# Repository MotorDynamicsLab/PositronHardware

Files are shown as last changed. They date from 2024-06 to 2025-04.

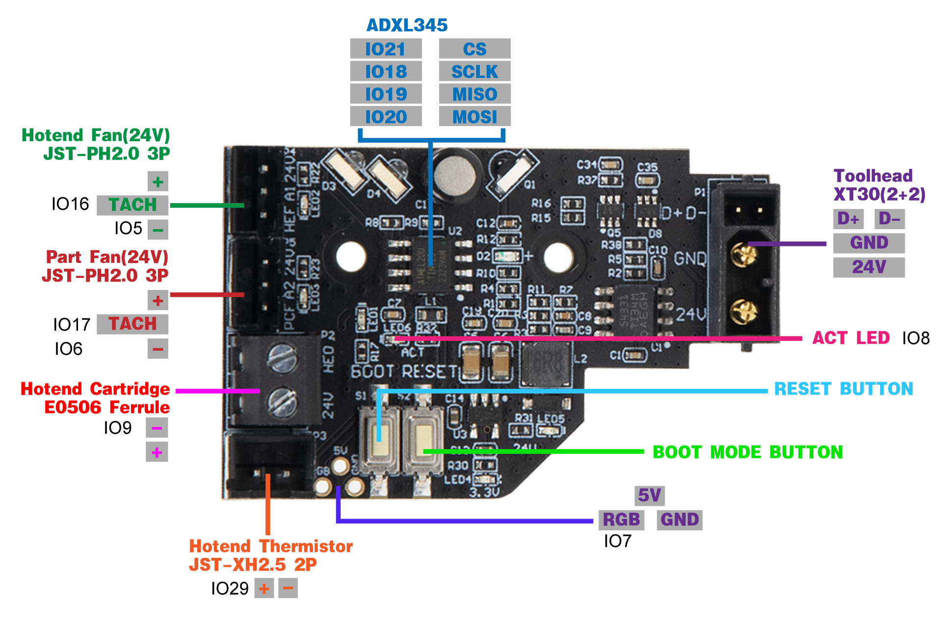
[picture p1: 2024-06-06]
PositronV3.2/Images/Toolboard Pinout.png

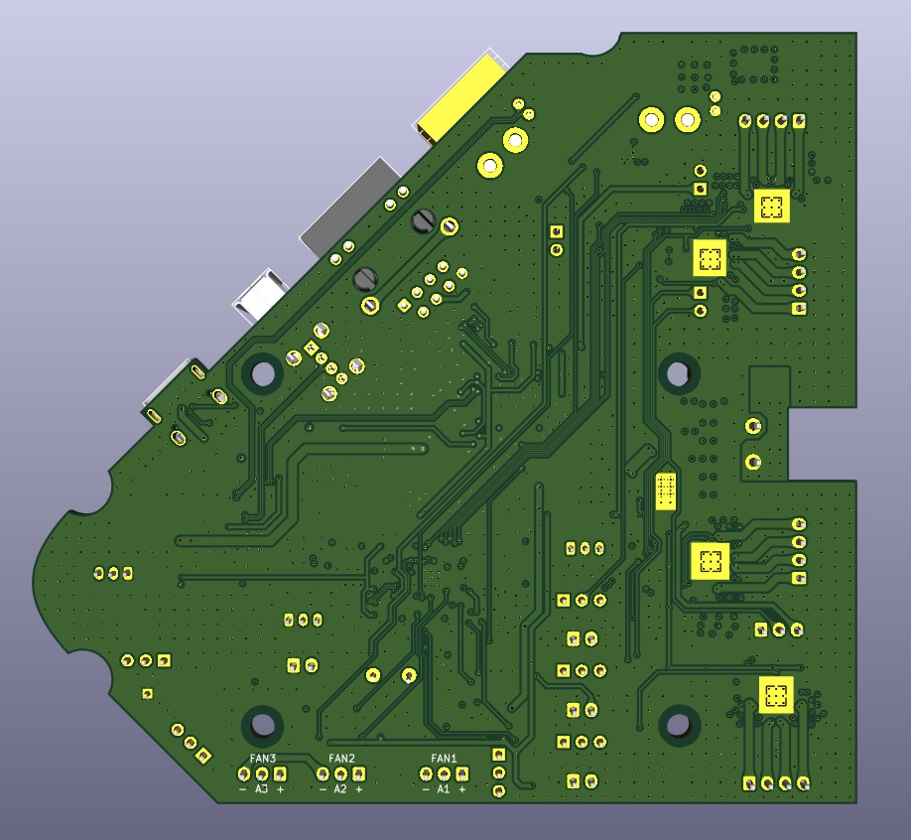
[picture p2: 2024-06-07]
PositronV3.2/Hardware/LDO Positron Mainboard/LDO Positron Mainboard Rev1.1_3D Layout Bottom.jpg

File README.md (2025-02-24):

# Positron Hardware
Contains information and drawings for PCBs used in the LDO Positrons

## Exceptions to CC BY-SA 4.0 for LDO Motors – Positron 3D PCBs

The Positron 3D Team grants an exception to the CC BY-SA 4.0 license for PCBs developed for the Positron 3D printer and manufactured by LDO Motors under the following conditions:
1. Limited Scope: This exception applies only to PCB designs developed by the Positron 3D Team and manufactured by LDO Motors. All other components remain under CC BY-SA 4.0.
2. No ShareAlike Requirement: Modifications or derivatives of these PCBs do not need to be shared under CC BY-SA 4.0.
3. Commercial Use Restriction: Manufacturing and resale of these PCBs are limited to LDO Motors and authorized distributors. Personal, non-commercial use is permitted.
4. Attribution Requirement: Any use of these PCB designs must credit Positron 3D Team and LDO Motors per CC BY-SA 4.0.
5. No Warranty: The Positron 3D Team and LDO Motors provide the PCBs as-is, with no guarantees. Users assume all risks.

This exception ensures manufacturing consistency while maintaining open-source principles. For licensing inquiries, contact Positron 3D Team or LDO Motors.

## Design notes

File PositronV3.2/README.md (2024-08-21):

# Positron V3.2

This directory contains information about PCBs used in the Positron V3.2.

The Positron system consists of three PCBs, a touch controller and the umbilical cables. 

- **LDO Positron Mainboard**, It is a motherboard specifically designed for PV3.2 kits. It features Raspberry Pi Arm Cortex-M0+ RP2040 MCU, with 4 TMC2209 stepper drivers and 3 fan ports. It also features an onboard USB hub which expands the RPI host connectivity with ethernet and an USB A port.
- **PV3 Toolhead PCB**, It is a toolboard PCB specifically designed for the PV3.2 kits. It features RP2040 MCU and ADXL345 accelerometer all integrated into one board.
- **PV3 Switch PCB**, It controls the printer switch and reduce the current thus preventing the switch from overheating.
- **Umbilical Cable**, It is a custom flex cable that is rated for drag chain use. It delivers 24V power to the toolhead PCB while also carrying USB data.
- **PV3 Touch Controller**,  It features a touch screen with a Raspberry Pi CM4.

## Features

- **Convenient wiring**, wire up the entire printer with a few simple cables.
- **USB Klipper connection**, no additional software or hardware setup.
- **Exposed Connectivity**, with a PCB form factor designed specifically for the Positron, USB and ethernet ports are directly exposed and allow for easy connections

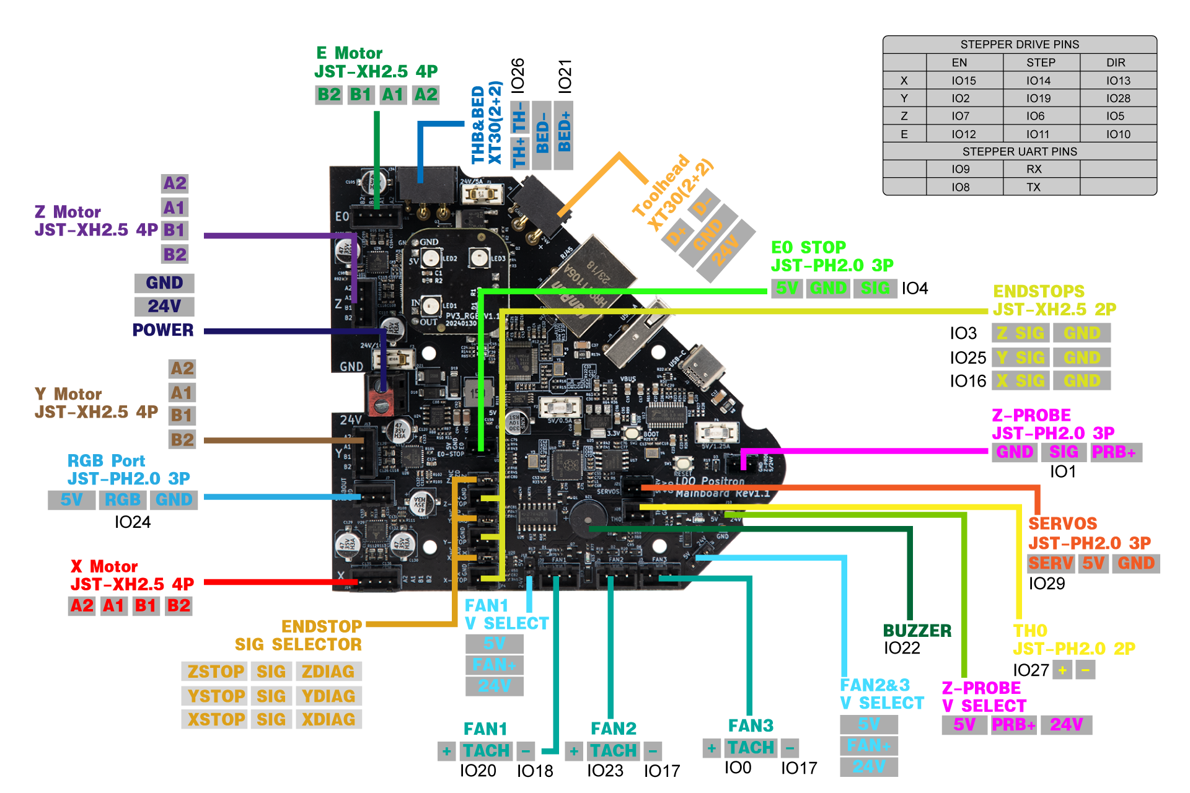
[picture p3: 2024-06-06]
PositronV3.2/Images/Mainboard Pinout.png

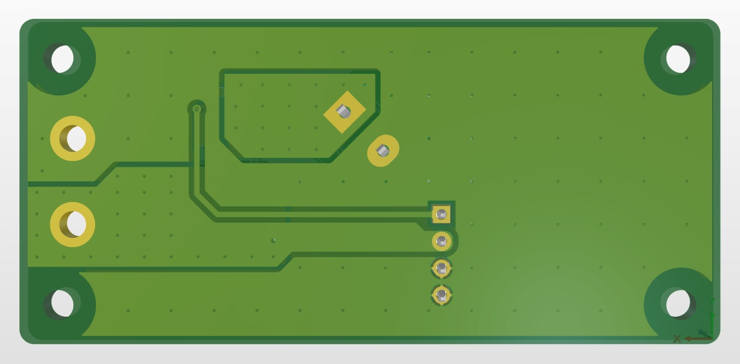
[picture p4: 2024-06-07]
PositronV3.2/Hardware/PV3 Switch Board/PV3 Switch PCB Ver1.1_3D Layout Bottom.jpg

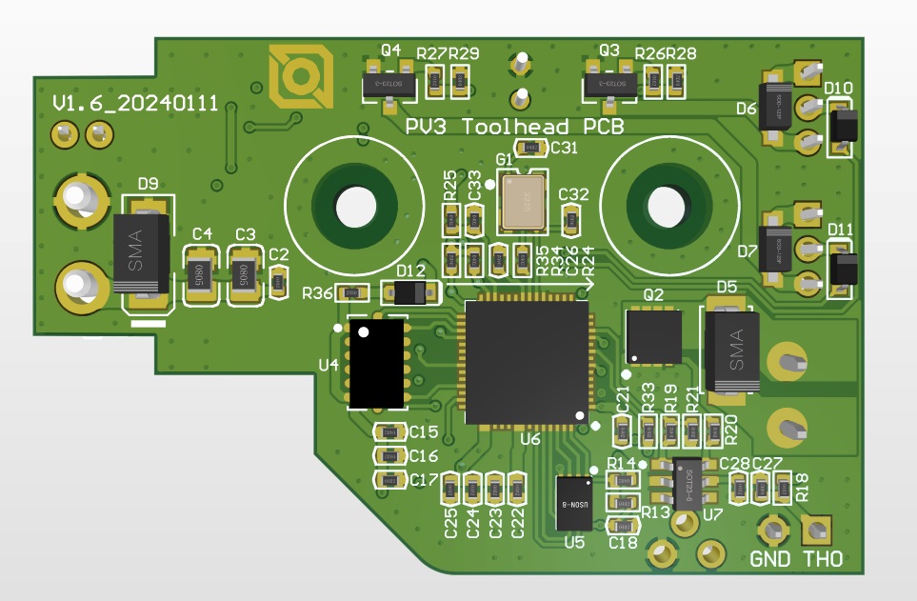
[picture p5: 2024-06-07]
PositronV3.2/Hardware/PV3 Tool Board/PV3 Toolhead PCB V1.6_3D Layout Bottom.jpg

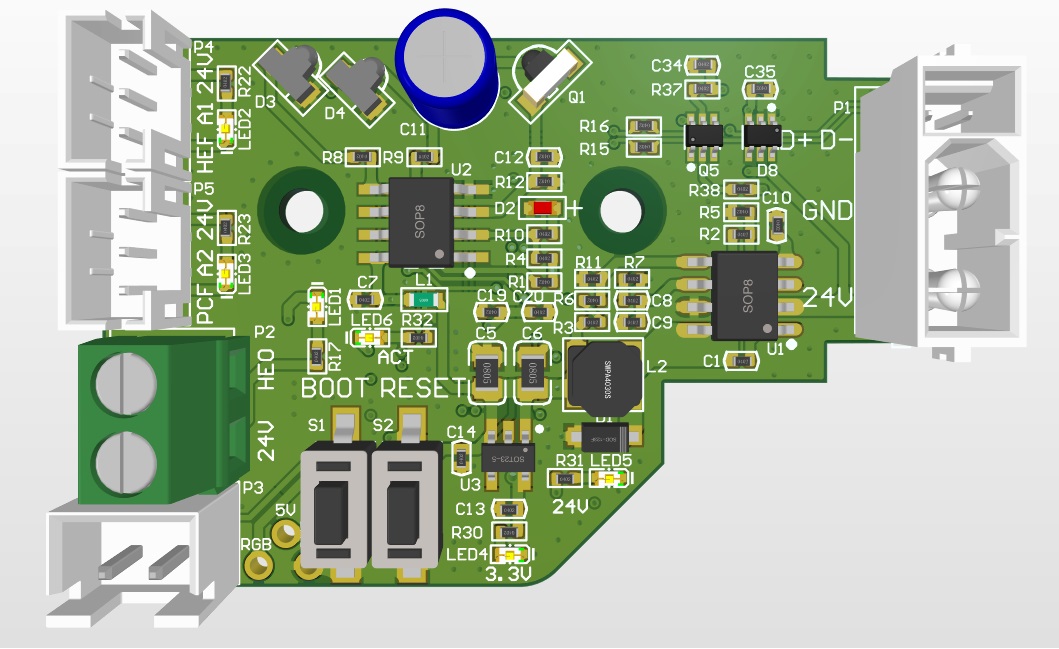
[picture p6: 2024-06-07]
PositronV3.2/Hardware/PV3 Tool Board/PV3 Toolhead PCB V1.6_3D Layout Top.jpg

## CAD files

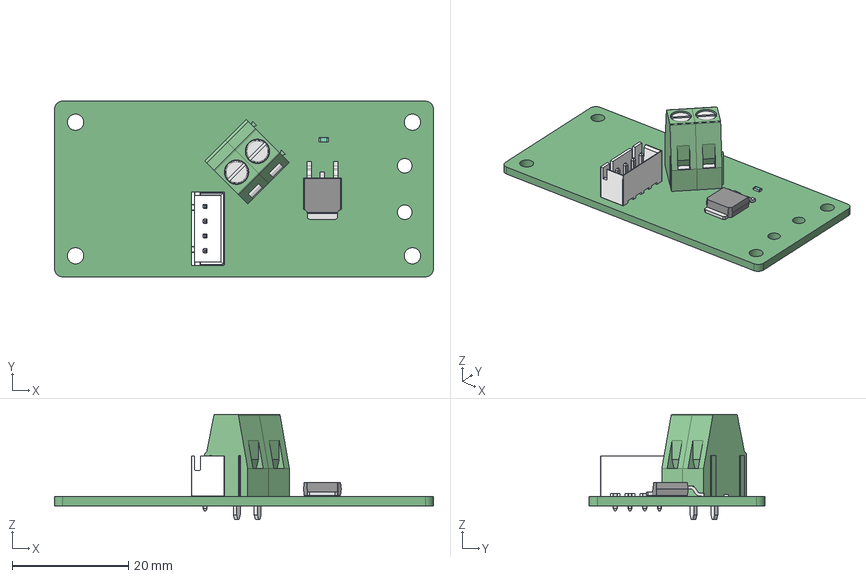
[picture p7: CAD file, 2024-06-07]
PositronV3.2/Hardware/PV3 Switch Board/PV3 Switch PCB Ver1.1_3D Model.step
65.3 x 30.3 x 18.1 mm
TO-252
LOGO? x 2
XH2.54-4P
R_0603
KF128-5.08 x 2
LOGO?0.75 x 2

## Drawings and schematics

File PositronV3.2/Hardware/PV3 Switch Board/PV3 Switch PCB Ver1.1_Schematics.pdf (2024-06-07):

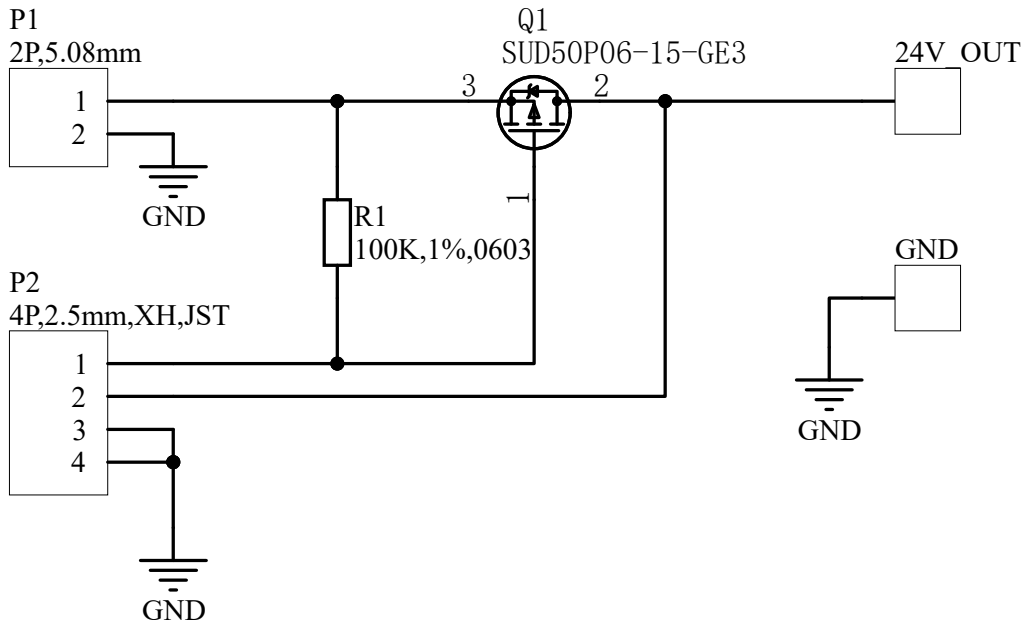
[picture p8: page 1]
Title; SUD50P06-15-GE3; P2 4P,2.5mm,XH,JST; GND; 24V_OUT

Size A4 | Number | Revision

Date: 6/07/2024 | Sheet of
File: D:\LDO_Work\..\PV3 Switch PCB Ver1.1_20240130.SchDoc Drawn By:

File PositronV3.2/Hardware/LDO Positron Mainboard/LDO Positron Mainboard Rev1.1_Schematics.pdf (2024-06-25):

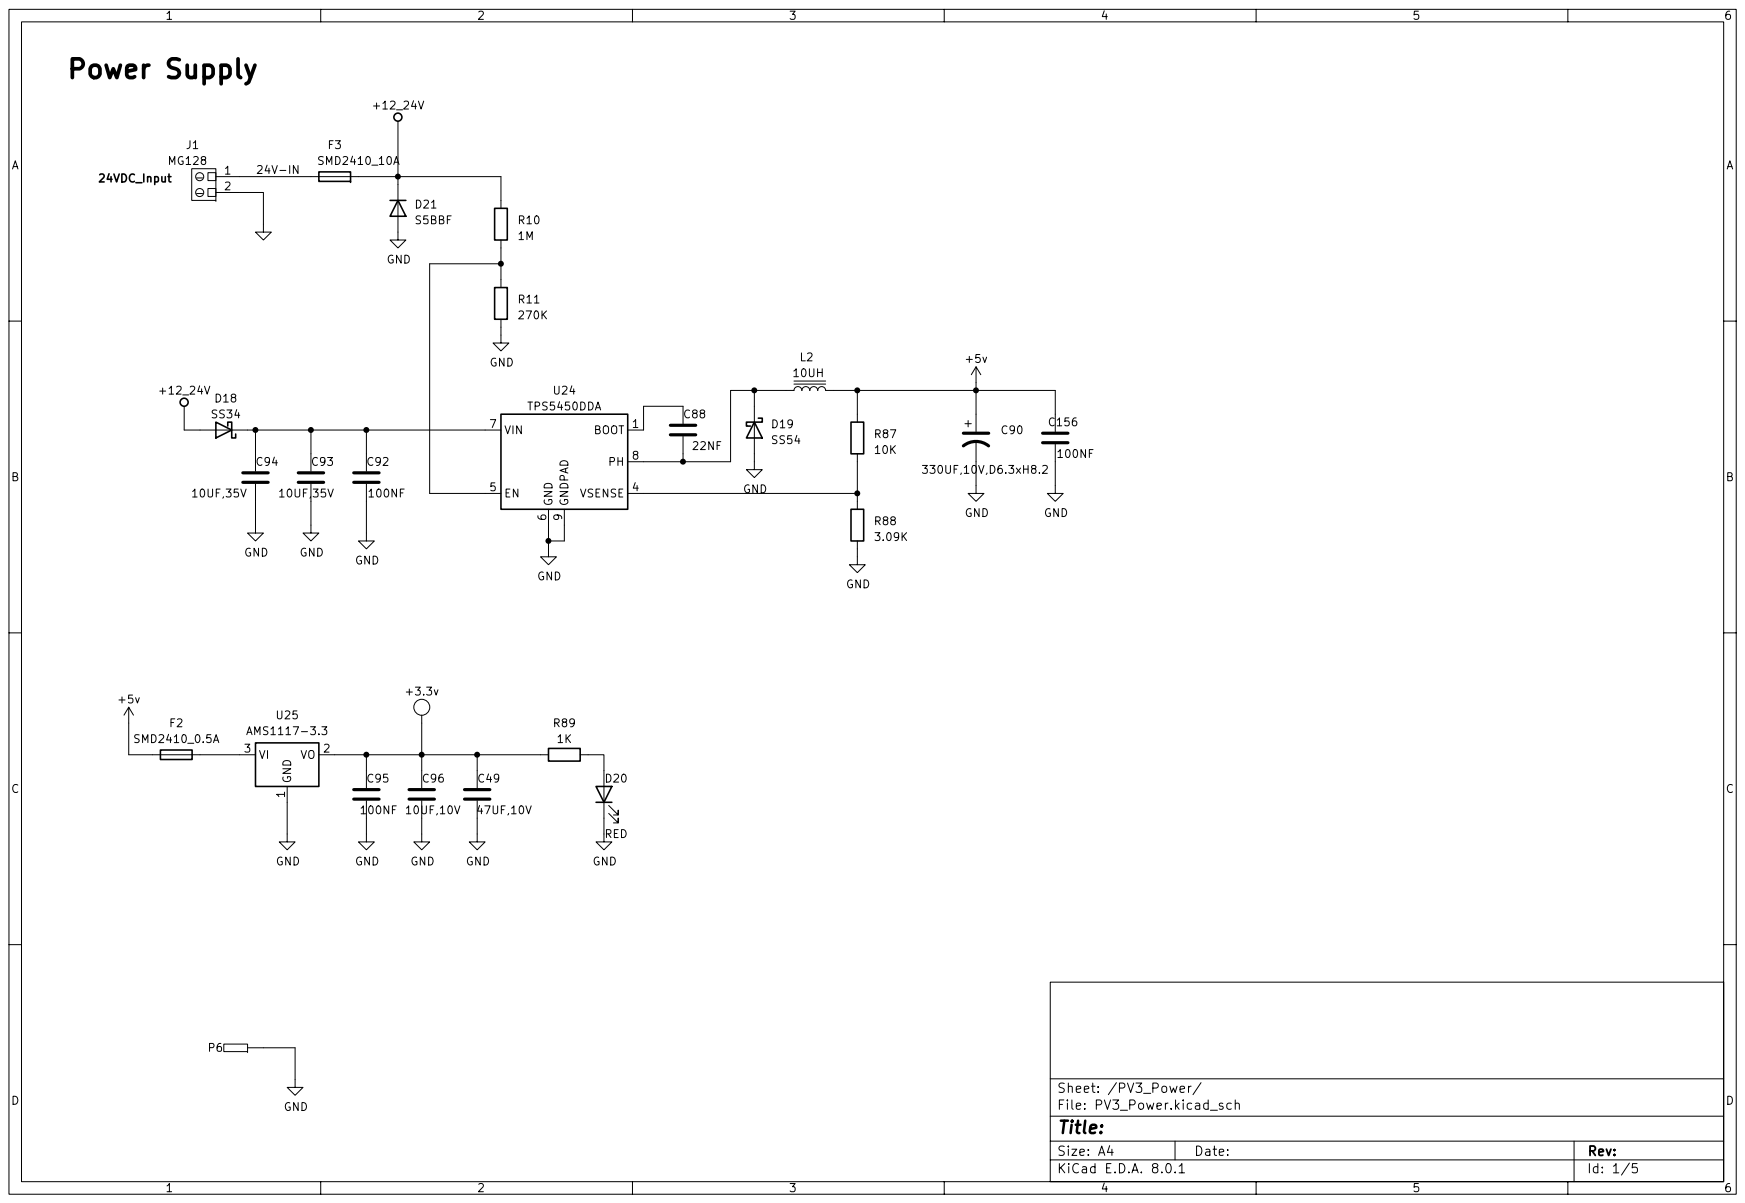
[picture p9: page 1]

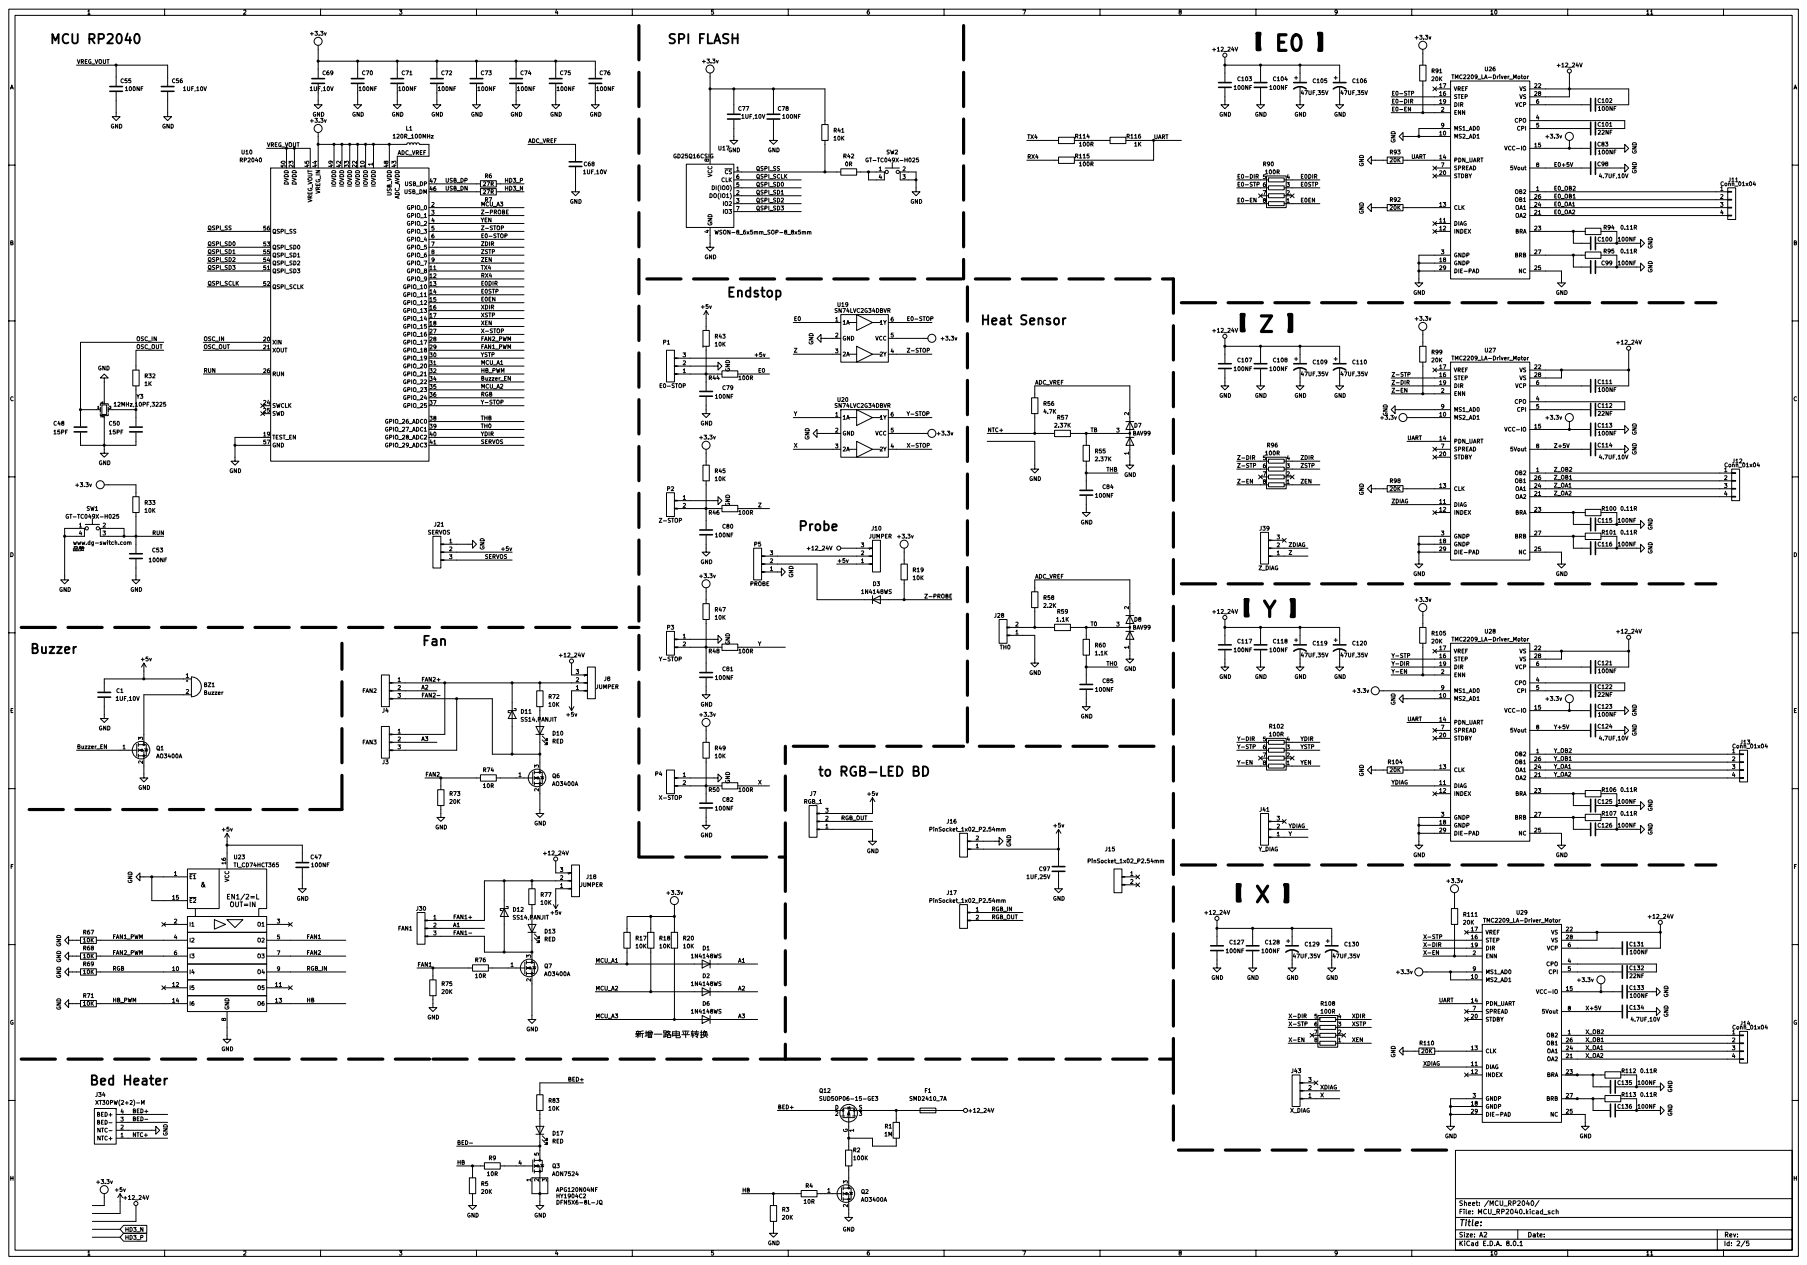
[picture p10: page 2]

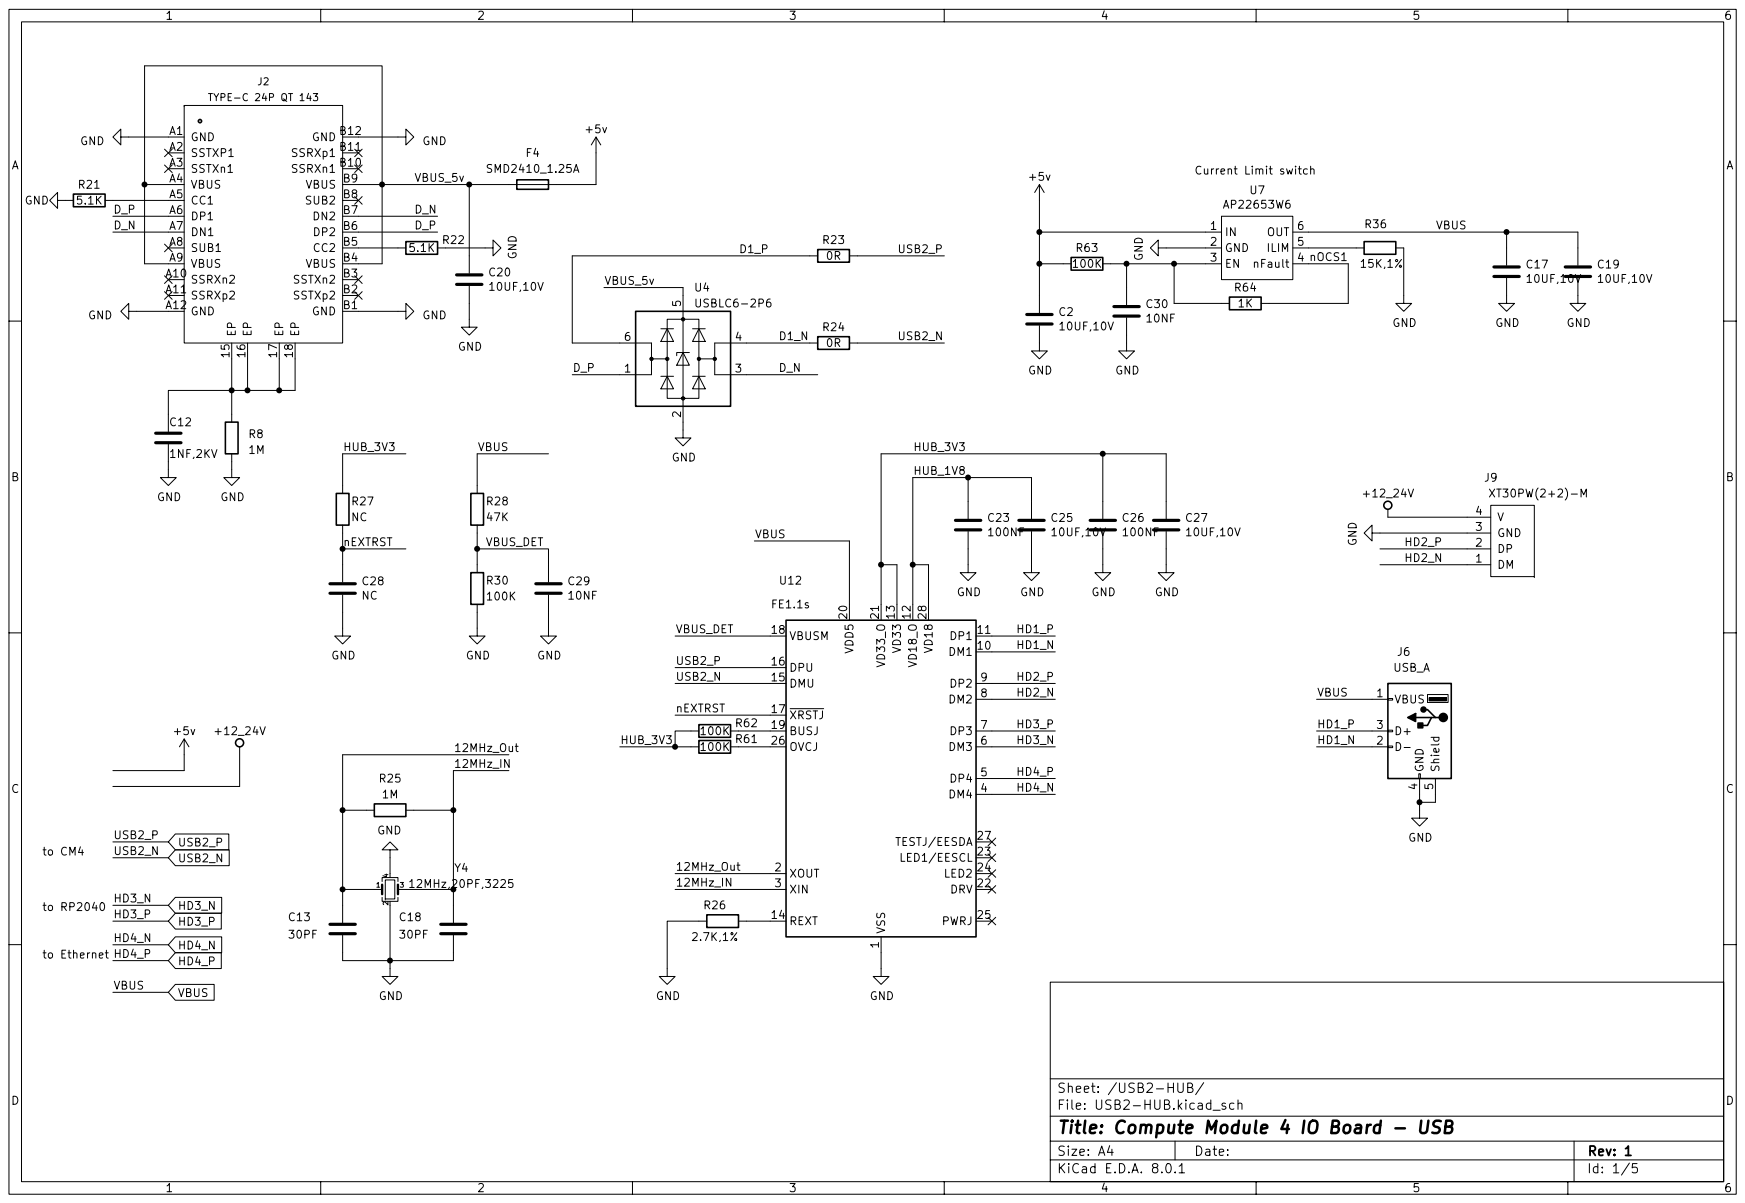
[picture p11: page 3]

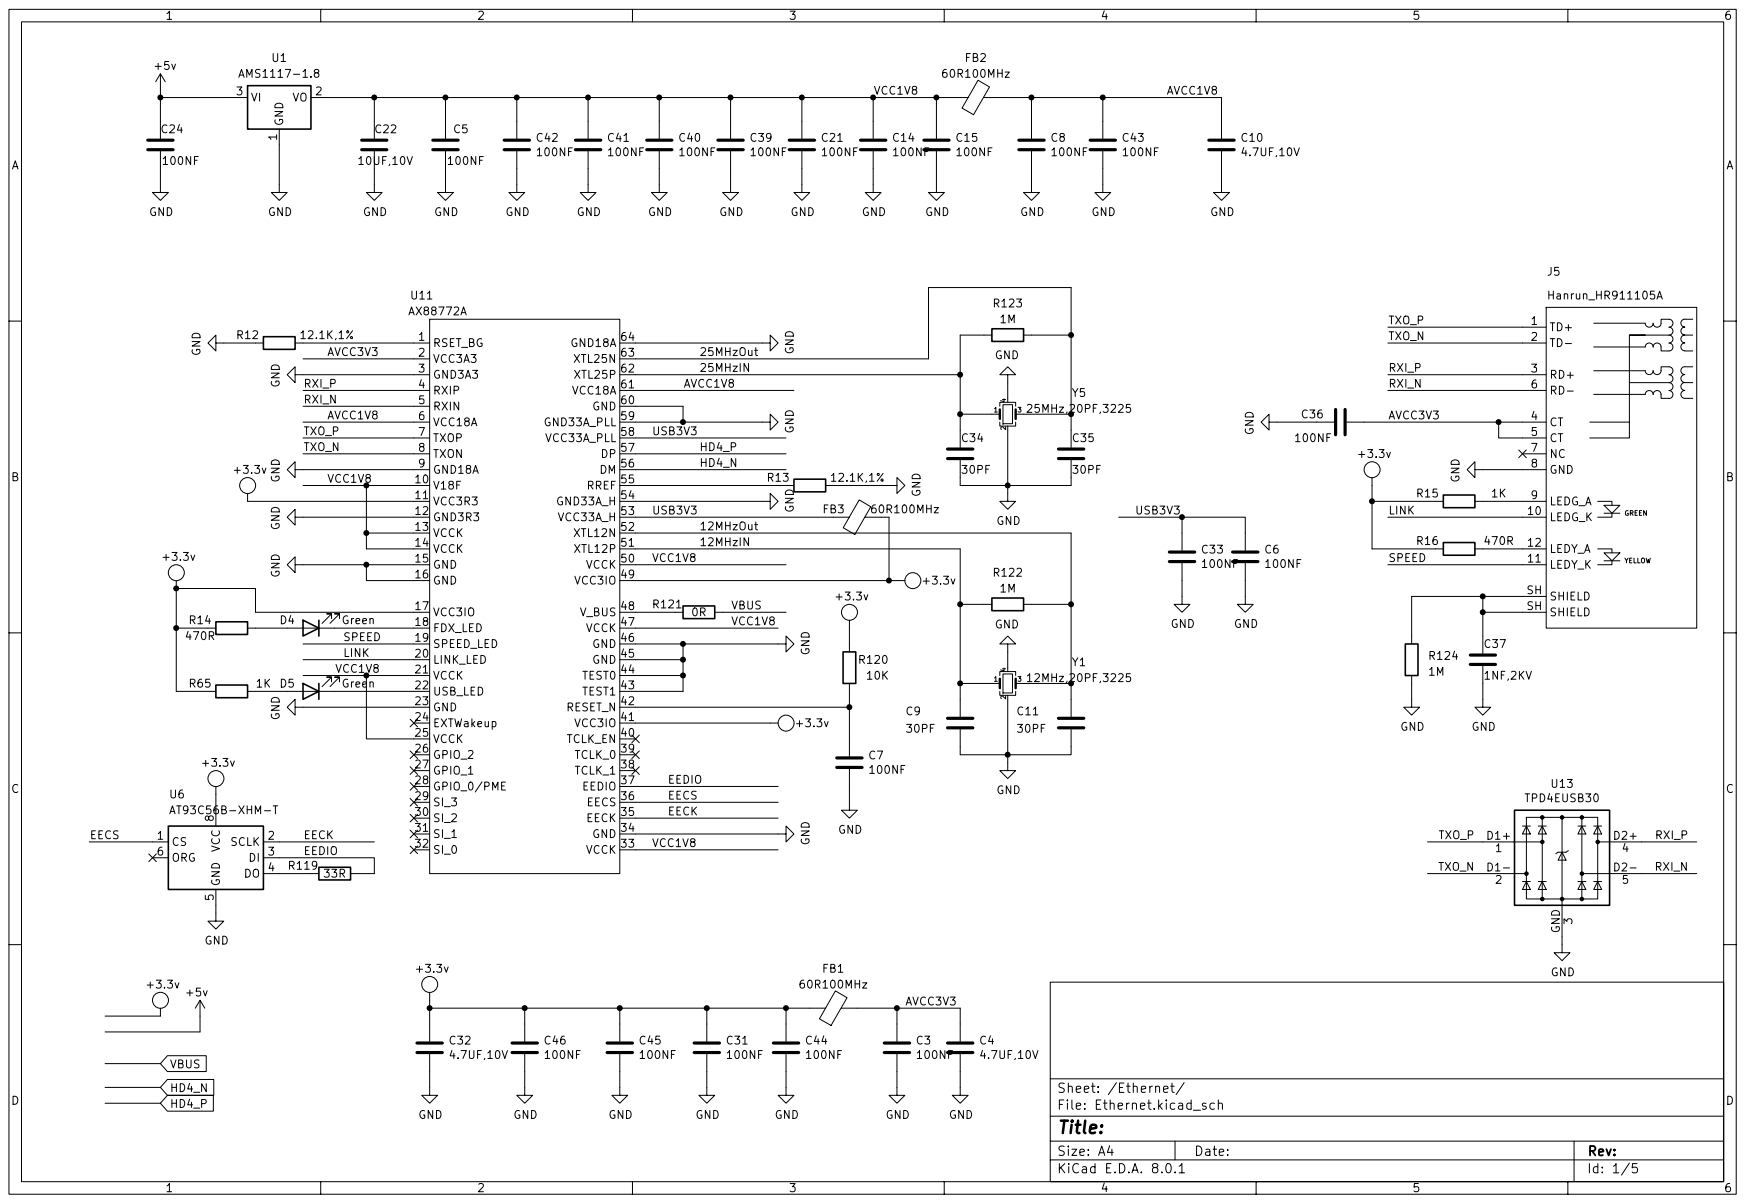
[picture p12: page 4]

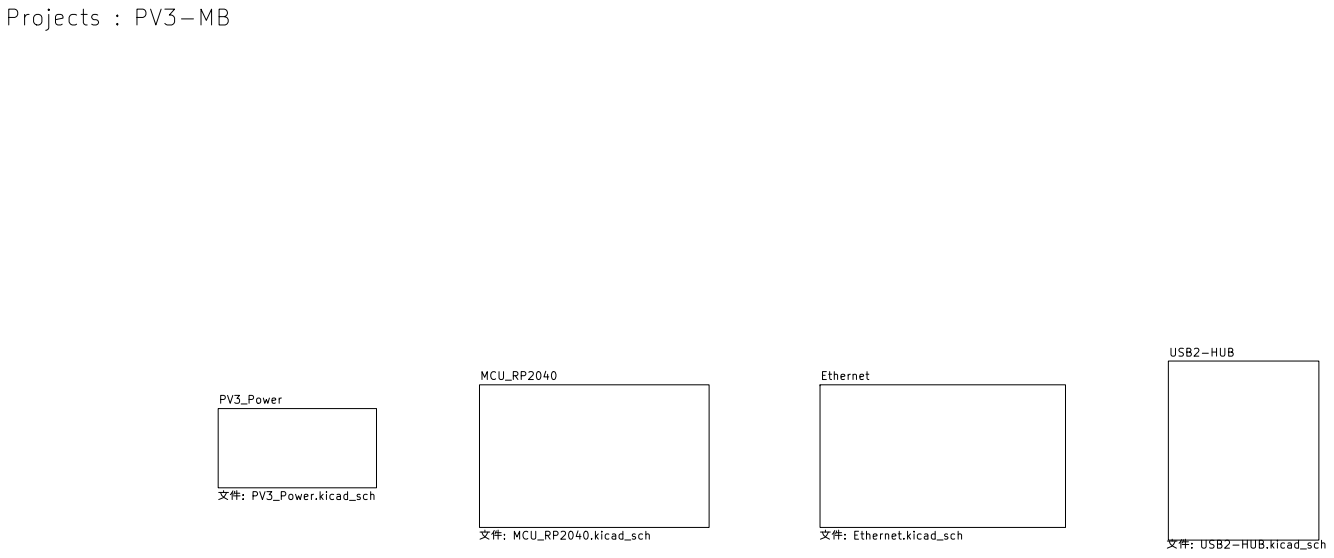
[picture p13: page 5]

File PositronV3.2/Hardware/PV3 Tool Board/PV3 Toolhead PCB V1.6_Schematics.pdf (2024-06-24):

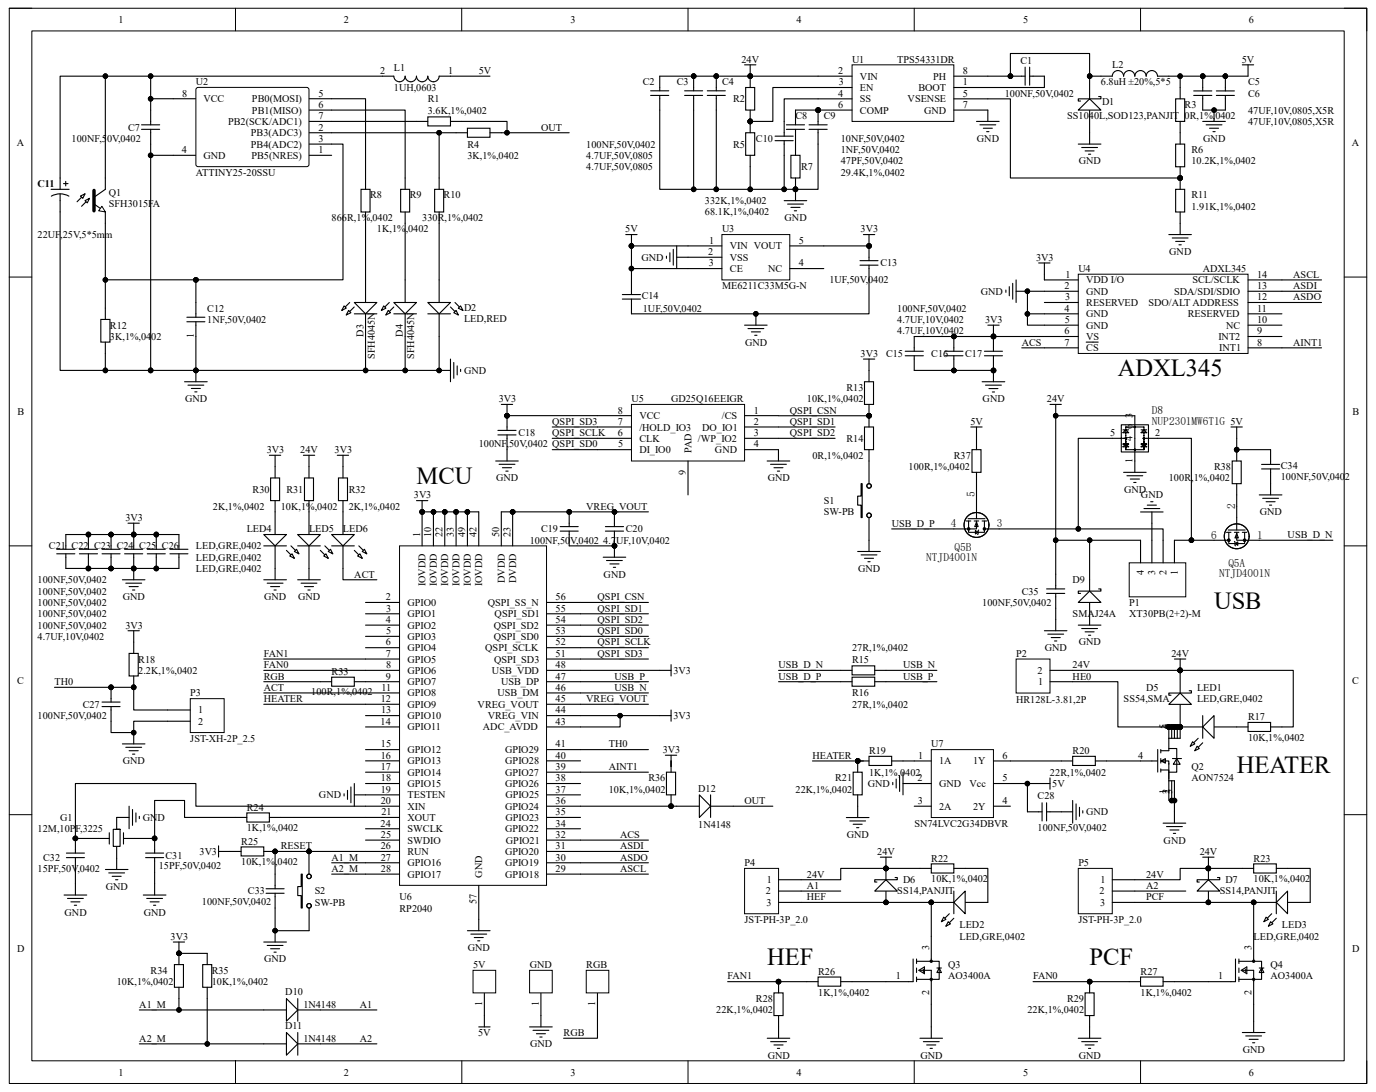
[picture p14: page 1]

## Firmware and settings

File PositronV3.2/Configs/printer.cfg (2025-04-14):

#####################################################################
#
#       @@\       @@@@@@@\   @@@@@@\  
#       @@ |      @@  __@@\ @@  __@@\ 
#       @@ |      @@ |  @@ |@@ /  @@ |
#       @@ |      @@ |  @@ |@@ |  @@ |
#       @@ |      @@ |  @@ |@@ |  @@ |
#       @@ |      @@ |  @@ |@@ |  @@ |
#       @@@@@@@@\ @@@@@@@  | @@@@@@  |
#       \________|\_______/  \______/ 
#                            
# 3D Printer Firmware Configuration
#
# This configuration file contains the basic settings for a stock
# LDO Positron 3D printer build. 
#  
# This file was generated for:
# LDO Positron V3 Rev A
#####################################################################


[include fluidd.cfg]
[virtual_sdcard]
path: /home/pi/printer_data/gcodes
on_error_gcode: CANCEL_PRINT


[mcu]
#####################################################################
# Obtain definition by "ls -l /dev/serial/by-id/"
#####################################################################
serial: /dev/serial/by-path/platform-fe9c0000.xhci-usb-0:1.3:1.0
restart_method: command
##--------------------------------------------------------------------

#####################################################################
#   LDO Positron Toolhead PCB
#####################################################################

[mcu pth]
##  Obtain definition by "ls -l /dev/serial/by-id/" then unplug to verify
##--------------------------------------------------------------------
serial: /dev/serial/by-path/platform-fe9c0000.xhci-usb-0:1.2:1.0
restart_method: command
##--------------------------------------------------------------------

#####################################################################
#   Printer Settings
#####################################################################

[printer]
kinematics: corexy
max_velocity: 420
max_accel: 8000
square_corner_velocity: 7
max_z_velocity: 20
max_z_accel: 150

#####################################################################
#      X/Y Stepper Settings
#####################################################################

[stepper_x]
step_pin: gpio14
dir_pin: !gpio13
enable_pin: !gpio15
microsteps: 16
rotation_distance: 40
endstop_pin: tmc2209_stepper_x:virtual_endstop
homing_retract_dist: 0
position_endstop: 0
position_max: 180
homing_speed: 40

[tmc2209 stepper_x]
uart_pin: gpio9
tx_pin: gpio8
uart_address: 3
run_current: 0.7
stealthchop_threshold: 999999
diag_pin: ^gpio16
driver_SGTHRS: 50                                          # Set to 999999 to turn stealthchop on, and 0 to use spreadcycle

[stepper_y]
step_pin: gpio19
dir_pin: !gpio28
enable_pin: !gpio2
microsteps: 16
rotation_distance: 40
endstop_pin: tmc2209_stepper_y:virtual_endstop
homing_retract_dist: 0
position_endstop: 180
position_max: 180
homing_speed: 40
homing_positive_dir: True

[tmc2209 stepper_y]
uart_pin: gpio9
tx_pin: gpio8
uart_address: 1
run_current: 0.7
stealthchop_threshold: 999999
diag_pin: ^gpio25
driver_SGTHRS: 50                                         # Set to 999999 to turn stealthchop on, and 0 to use spreadcycle

#####################################################################
#   Z Stepper Settings
#####################################################################

[stepper_z]
step_pin: gpio6
dir_pin: !gpio5
enable_pin: !gpio7
microsteps: 16
rotation_distance: 40
gear_ratio: 75:10
## Choose only one of the following lines for z homing ##
endstop_pin: probe:z_virtual_endstop     ; virtual endstop probe 
#endstop_pin: gpio3                      ; microswitch
#position_endstop: 14.0                  ; microswitch
position_min: -4.0
position_max: 165
homing_speed: 13

[tmc2209 stepper_z]
uart_pin: gpio9
tx_pin: gpio8
uart_address: 2
run_current: 0.25
stealthchop_threshold: 999999                                          # Set to 999999 to turn stealthchop on, and 0 to use spreadcycle

#####################################################################
#   Extruder
#####################################################################

[extruder]
step_pin: gpio11
dir_pin: gpio10
enable_pin: !gpio12
microsteps: 16
full_steps_per_rotation: 200
rotation_distance: 4.637
nozzle_diameter: 0.4
filament_diameter: 1.75
heater_pin: pth:gpio9
sensor_type: ATC Semitec 104NT-4-R025H42G
sensor_pin: pth:gpio29
pullup_resistor: 2200
control: pid
pid_Kp: 25.12
pid_Ki: 1.073
pid_Kd: 147
min_temp: -100
max_temp: 300
full_steps_per_rotation: 200
max_extrude_only_distance: 500
max_extrude_only_velocity: 120
max_extrude_cross_section:2
pressure_advance: 0.25

[tmc2209 extruder]
uart_pin: gpio9
tx_pin: gpio8
uart_address: 0
run_current: 0.62
hold_current: 0.4

#####################################################################
#   Bed Heater
#####################################################################

[thermistor SDNT2012X104_3950]
temperature1: 25
resistance1: 100000
beta: 3950

[heater_bed]
heater_pin: gpio21
sensor_type: SDNT2012X104_3950
sensor_pin: gpio26
pwm_cycle_time: 0.3
max_power: 1.0
control: pid
pid_Kp: 56.852
pid_Ki: 2.1
pid_Kd: 383.75
min_temp: 0
max_temp: 120

#####################################################################
#   Probe
#####################################################################

[probe]
pin: pth:gpio24
x_offset:0
y_offset: 0
z_offset: -3.100
speed: 3
samples: 6
sample_retract_dist: 0.7
samples_tolerance: 0.05
samples_result: median

#####################################################################
# Fan Control
#####################################################################

[controller_fan mcu_fan1]
pin: gpio17
max_power: 0.8
shutdown_speed: 0
kick_start_time: 1
fan_speed: 0.8
idle_timeout: 5
stepper: stepper_x, stepper_y, stepper_z

[controller_fan mcu_fan2]
pin: gpio18
max_power: 0.5
shutdown_speed: 0
kick_start_time: 1
fan_speed: 0.5
idle_timeout: 5
stepper: stepper_x, stepper_y, stepper_z

## HEF - Toolhead PCB
[heater_fan hotend_fan]
pin: pth:gpio5
max_power: 1.0
kick_start_time: 0.5
heater: extruder
fan_speed: 0.7

## PCF - Toolhead PCB
[fan]
pin: pth:gpio6
max_power: 0.8
kick_start_time: 0.5                                                # Depending on your fan, you may need to increase this value if your fan will not start
off_below: 0.13
cycle_time: 0.010

#####################################################################
#   LED Control
#####################################################################

[output_pin pcb_led]
pin: !pth:gpio8

[neopixel indicator]
pin: gpio24
chain_count: 5
color_order: GRB
initial_RED: 0.0
initial_GREEN: 0.0
initial_BLUE: 0.0

#####################################################################
#   Accelerometer
#####################################################################
[adxl345]
cs_pin: pth:gpio21
spi_software_sclk_pin: pth:gpio18
spi_software_mosi_pin: pth:gpio20
spi_software_miso_pin: pth:gpio19

[resonance_tester]
accel_chip: adxl345
probe_points:
    85, 85, 20

#####################################################################
# Homing and Gantry Adjustment Routines
#####################################################################

[idle_timeout]
timeout: 1800

# [safe_z_home]
# home_xy_position: 120,120
# speed: 50.0
# z_hop: 5

## To be used with BED_SCREWS_ADJUST
[bed_screws]
screw1: 5,170
screw1_name: fl
screw2: 180,170
screw2_name: fr
screw3: 90,20
screw3_name: bm

[screws_tilt_adjust]
    screw1: 41,1
    screw1_name: bm
    screw2: 0,122
    screw2_name: fl
    screw3: 81,122
    screw3_name: fr
    screw_thread: CCW-M3

#####################################################################
#   Buzzer
#####################################################################

## Buzzer
[output_pin beeper]
pin: gpio22
value: 0
shutdown_value: 0

#####################################################################
#   Additional Sensors
#####################################################################

#####################################################################
#   Bed Adjustment Routines
#####################################################################
[bed_mesh]
speed: 220
horizontal_move_z: 5
mesh_min: 0, 10
mesh_max: 116, 106
probe_count: 4, 4

# [bed_tilt]
# points: 
#   0, 20
#   116, 20
#   116, 106
#   0,  106
# speed: 150
# horizontal_move_z: 4

[display_status]
[pause_resume]
[include sensorless_homing_pv3.cfg]
[include positron_macros.cfg]
[exclude_object]

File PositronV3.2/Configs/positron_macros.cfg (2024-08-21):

## LDO recommended macros to get you started
# These macros are recommended by LDO
# You can copy these entries into your printer.cfg.
# 
# Alternatively, 
# You can copy these entries into your printer.cfg.
# 
[gcode_macro M300]
description: Implements M300 gcode which allows beeper to be used
gcode:
    {% set TIME_MS = params.P|default(100)|float %}
    SET_PIN PIN=beeper VALUE=1
    G4 P{TIME_MS}
    SET_PIN PIN=beeper VALUE=0


[gcode_macro M600]
description: Implements M600 gcode (pause & filament change)
gcode: 
  pause
  SAVE_GCODE_STATE NAME=M600
  G91                         ; relative positioning
  G1 Z20                      ; move nozzle upwards
  FRONT                       ; move the toolhead to the front
  M83                         ; set extruder to relative mode
  G1 E10 F300                 ; extrude a little to soften tip
  G1 E-30 F3000               ; quickly retract a small amount to elimate stringing
  G4 P200                     ; pause for a short amount of time
  G1 E-100 F1200              ; retract slowly the rest of the way
  G1 E-100 F1200
  G1 E-100 F1200
  G1 E-100 F1200
  M400                        ; wait for moves to finish
  RESTORE_GCODE_STATE NAME=M600
  M117 Unload Complete!


[gcode_macro CHOME]
description: Homes XYZ axis only if printer is in a non-homed state
gcode:
  {% if "xyz" not in printer.toolhead.homed_axes %}
    G28
  {% endif %}


[gcode_macro CENTER]
description: Moves the toolhead to the center
gcode:
  CHOME
  {% set x_center = printer.toolhead.axis_maximum.x|float / 2.0 %}
  {% set y_center = printer.toolhead.axis_maximum.y|float / 2.0 %}
  G90
  G1 X{x_center} Y{x_center} F7800


[gcode_macro FRONT]
description: Moves the toolhead to the front
gcode:
  CHOME
  {% set x_center = printer.toolhead.axis_maximum.x|float / 2.0 %}
  {% set y_front = printer.toolhead.axis_maximum.y|float - 10 %}
  G90
  G1 X{x_center} Y{y_front} F7800


[gcode_macro NOZZLE_PURGE]
description: Draw a purge line at the front left edge of the build plate
gcode:
  CHOME
  SAVE_GCODE_STATE NAME=NOZZLE_PURGE
  G90                     ; Use absolute coordinates
  G0 X5 Y40 F7200         ; Go to side
  G0 Z0.2                 ; Drop to bed
  M83                     ; Set extruder to relative mode
  G1 X5 Y135 E30 F800     ; print prime line
  G1 E-0.5 F400           ; Retract a little
  G1 Y170 F4000           ; Quickly wipe away from the filament line
  G1 Z0.4                 ; Raise and begin printing.
  RESTORE_GCODE_STATE NAME=NOZZLE_PURGE

[gcode_macro NOZZLE_DOCK]
description: Docks the nozzle at the corner of the bed to prevent ooze
variable_dock_x: 3.5
variable_dock_y: 1.0
variable_dock_z: 1.0
gcode:
  CHOME
  SAVE_GCODE_STATE NAME=NOZZLE_DOCK
  G91                           ; relative positioning
  G1 Z5                         ; move nozzle upwards slightly
  G90                           ; relative positioning
  G0 X{dock_x} Y{dock_y} F7200  ; Go dock position
  G0 Z{dock_z}                       ; Use absolute coordinates
  RESTORE_GCODE_STATE NAME=NOZZLE_DOCK

[gcode_macro NOZZLE_UNDOCK]
description: Safely moves the nozzle out of its docking position
gcode:
  CHOME
  SAVE_GCODE_STATE NAME=NOZZLE_UNDOCK
  G91                           ; relative positioning
  G1 Z3                         ; move nozzle upwards slightly
  RESTORE_GCODE_STATE NAME=NOZZLE_UNDOCK


[gcode_macro UNLOAD_FILAMENT]
description: Unloads filament from toolhead. Hotend is not preheated, if TEMP parameter is set to 0
gcode:
  {% set EXTRUDER_TEMP = params.TEMP|default(220)|int %}
  {% set MIN_TEMP = params.TEMP|default(220)|float * 0.98 %}
  {% set CURRENT_TARGET = printer.extruder.target|float %}
  SAVE_GCODE_STATE NAME=UNLOAD_FILAMENT
  CHOME
  G91                         ; relative positioning
  G1 Z20                      ; move nozzle upwards
  FRONT                       ; move the toolhead to the front

  {% if EXTRUDER_TEMP != 0 %}
    LED_PENDING
    {% if CURRENT_TARGET < EXTRUDER_TEMP %}
      M104 S{EXTRUDER_TEMP} ; only heat up if the current extruder is not already hot
    {% endif %}
    TEMPERATURE_WAIT SENSOR="extruder" MINIMUM={MIN_TEMP} ; wait for min extrude temp to reach
  {% endif %}
  LED_WORKING
  M83                         ; set extruder to relative mode
  G1 E10 F300                 ; extrude a little to soften tip
  G1 E-30 F3600               ; quickly retract a small amount to elimate stringing
  G4 P200                     ; pause for a short amount of time
  G1 E-400 F1200              ; retract slowly the rest of the way
  M400                        ; wait for moves to finish
  RESTORE_GCODE_STATE NAME=UNLOAD_FILAMENT
  M300 P1000                  ; long beep to indicate unload complete
  M117 Unload Complete!
  LED_READY


[gcode_macro LOAD_FILAMENT]
description: Loads new filament into toolhead. Hotend is not preheated, if TEMP parameter is set to 0
gcode:
  {% set EXTRUDER_TEMP = params.TEMP|default(220)|int %}
  {% set MIN_TEMP = params.TEMP|default(220)|float * 0.98 %}
  {% set CURRENT_TARGET = printer.extruder.target|float %}
  SAVE_GCODE_STATE NAME=LOAD_FILAMENT
  CHOME
  G91                         ; relative positioning
  G1 Z20                      ; move nozzle upwards
  FRONT                       ; move the toolhead to the front
  
  {% if EXTRUDER_TEMP != 0 %}
    LED_PENDING
    {% if CURRENT_TARGET < EXTRUDER_TEMP %}
      M104 S{EXTRUDER_TEMP} ; only heat up if the current extruder is not already hot
    {% endif %}
    TEMPERATURE_WAIT SENSOR="extruder" MINIMUM={MIN_TEMP} ; wait for min extrude temp to reach
  {% endif %}
  LED_WORKING
  M83                         ; set extruder to relative mode             
  G1 E400 F1200               ; extrude slowly
  G1 E20 F600
  M400                        ; wait for moves to finish
  RESTORE_GCODE_STATE NAME=LOAD_FILAMENT
  M300 P200                   ; two short beeps to indicate load complete
  G4 P100
  M300 P200
  M117 Load Complete!
  LED_READY


[gcode_macro G29]
description: Loads new filament into toolhead. Hotend is not preheated, if TEMP parameter is set to 0
gcode:
  CHOME
  #BED_MESH_CLEAR
  #G1 Z5 F800
  #BED_MESH_CALIBRATE
  #G28 Z


[gcode_macro PRINT_START]
description: print startup sequence
gcode:
  {% set BED_TEMP = params.BED|default(65)|float %}
  {% set READY_TEMP = params.BED|default(65)|float * 0.92 %}
  {% set EXTRUDER_TEMP = params.EXTRUDER|default(190)|float %}

  SAVE_GCODE_STATE NAME=STATE_PRINT_START
  LED_PENDING
  M107                              ; turn off part fan
  M140 S{BED_TEMP}                  ; set bed temperature and continue
  M104 S150                         ; set hotend slightly
  G29                               ; Level bed and homing sequence
  TEMPERATURE_WAIT SENSOR="heater_bed" MINIMUM={READY_TEMP} ;Wait for bed to mostly heat up 

  NOZZLE_DOCK                       ; Move the nozzle to docking position
  M109 S{EXTRUDER_TEMP}             ; wait for hot end temperature to reach final target
  M190 S{BED_TEMP}                  ; Wait for bed to reach temperature
  NOZZLE_UNDOCK                     ; Undock the nozzle 

  G90                               ; Use absolute coordinates
  RESTORE_GCODE_STATE NAME=STATE_PRINT_START
  LED_WORKING
  NOZZLE_PURGE


[gcode_macro PRINT_END]
description: print finish sequence
gcode:
  {% set th = printer.toolhead %}
  {% set x_safe = th.position.x + 20 * (1 if th.axis_maximum.x - th.position.x > 20 else -1) %}
  {% set y_safe = th.position.y + 20 * (1 if th.axis_maximum.y - th.position.y > 20 else -1) %}
  {% set z_safe = [th.position.z + 2, th.axis_maximum.z]|min %}
  {% set y_final = th.axis_maximum.y - 1 %}
  {% set z_final = [th.position.z + 50, th.axis_maximum.z]|min %}
  
  SAVE_GCODE_STATE NAME=STATE_PRINT_END
  M400                                     ; wait for buffer to clear
  G92 E0                                   ; zero the extruder
  G1 E-5.0 F2600                           ; retract filament
  TURN_OFF_HEATERS

  G90                                      ; absolute positioning
  G0 X{x_safe} Y{y_safe} Z{z_safe} F20000  ; move nozzle to remove stringing
  G0 X5 Y{y_final} F3600                   ; park the toolhead to the front corner
  G0 Z{z_final} F600                       ; raise the bed
  
  M107                                     ; turn off part fan
  LED_COMPLETE
  RESTORE_GCODE_STATE NAME=STATE_PRINT_END
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

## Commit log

2024-06-07 add hardware files and klipper configure
    [PV3 Switch PCB Ver1.1_3D Model.step, positron_macros.cfg, printer.cfg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]
2024-06-20 add tacho_macros.cfg
    [tacho_macros.cfg]
2024-06-24 update schematics
2024-06-27 Update the homing_override field to adapt to both infrared and pushbutton limits.
    [printer.cfg, sensorless_homing_pv3.cfg]
2024-07-08 update configure
    [printer.cfg]
2024-07-17 Added PCB information and feature
2024-07-22 fix z home in z trigger
    [sensorless_homing_pv3.cfg]
2024-08-21 Modify pumpback parameters，Change z levelling method
    [positron_macros.cfg, printer.cfg]
2024-08-21 remove up z operation
    [positron_macros.cfg]
2024-12-11 add [screws_tilt_adjust] configure
    [printer.cfg]
2025-01-18 Reduce fan Power
    [printer.cfg]
2025-02-24 Update README.md
    Clarify licensing for PCBs
2025-04-14 Update printer.cfg
    update x maximum x-axis travel range
    [printer.cfg]
